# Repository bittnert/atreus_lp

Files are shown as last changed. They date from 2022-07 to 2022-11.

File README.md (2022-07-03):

# Atreus Low Profile Keyboard

This repository contains the files for a low profile variant of the atreus keyboard. THe original atreus keyboard can be found [[https://gitlab.com/technomancy/atreus][here]].

** The low profile atreus keyboard is still under development. The first PCB version has been ordered but not build or tested yet. **

The Keyboard uses Kailh Choc key switches which are soldered into a PCB. An addressable LED can be added to each key switch. Due to the size constraints, only 2020 LEDs (or smaller) can be used.

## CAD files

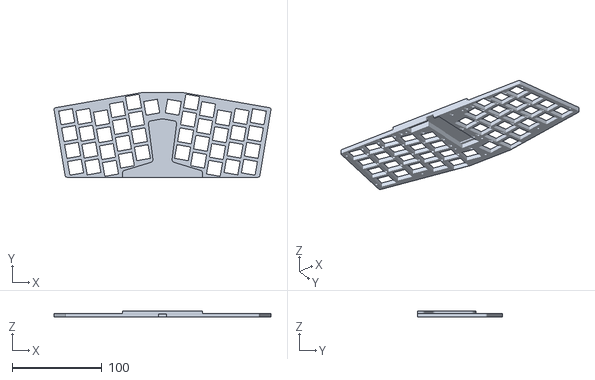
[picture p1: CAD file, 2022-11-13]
case/case.stl
241.4 x 94.0 x 6.60

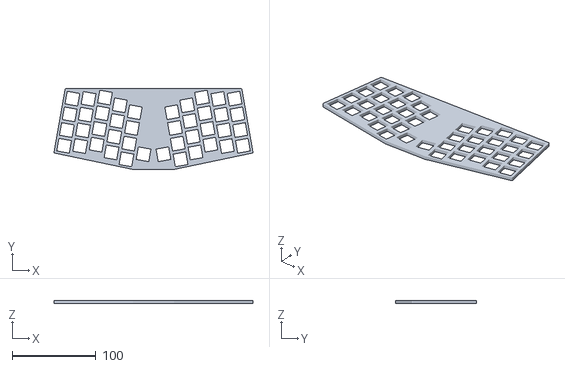
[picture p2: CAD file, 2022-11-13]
case/switch_plate.stl
237.0 x 96.3 x 3.50

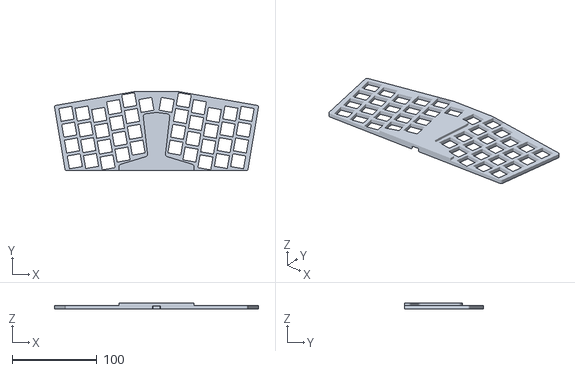
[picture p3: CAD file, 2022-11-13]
case/test_switch_plate.stl
241.4 x 94.0 x 6.60

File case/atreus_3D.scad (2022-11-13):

// -*- mode: c -*-
/* All distances are in mm. */

/* set output quality */
$fn = 50;

/* Distance between key centers. */
column_spacing   = 19;
row_spacing      = column_spacing;

/* This number should exceed row_spacing and column_spacing. The
 default gives a 1mm = (20mm - 19mm) gap between keycaps and cuts in
 the top plate.*/
key_hole_size = 20;

/* rotation angle; the angle between the halves is twice this
   number */
angle = 10;

/* The radius of screw holes. Holes will be slightly bigger due
   to the cut width. */
screw_hole_radius = 0;// 1.5;
/* Each screw hole is a hole in a "washer". How big these "washers"
   should be depends on the material used: this parameter and the
   `switch_hole_size` determine the spacer wall thickness. */
//washer_radius     = 4 * screw_hole_radius;
washer_radius = 1;

/* This constant allows tweaking the location of the screw holes near
   the USB cable. Only useful with small `angle` values. Try the value
   of 10 with angle=0. */
back_screw_hole_offset = 0;

/* Distance between halves. */
hand_separation        = 0;

/* The approximate size of switch holes. Used to determine how
   thick walls can be, i.e. how much room around each switch hole to
   leave. See spacer(). */
switch_hole_size = 14;

/* Sets whether the case should use notched holes. As far as I can
   tell these notches are not all that useful... */
use_notched_holes = false;

/* Number of rows and columns in the matrix. You need to update
   staggering_offsets if you change n_cols. */
n_rows = 4;
n_cols = 5;

/* Number of thumb keys (per hand), try 1 or 2. */
n_thumb_keys = 1;

/* The width of the USB cable hole in the spacer. */
cable_hole_width = 12;

/* Vertical column staggering offsets. The first element should
   be zero. */
staggering_offsets = [0, 5, 11, 6, 3];

/* Whether or not to split the spacer into quarters. */
quarter_spacer = false;

/* Where the top/bottom split of a quartered spacer will be. */
spacer_quartering_offset = 60;

module rz(angle, center=undef) {
  /* Rotate children `angle` degrees around `center`. */
  translate(center) {
    rotate(angle) {
      translate(-center) {
        for (i=[0:$children-1])
          children(i);
      }
    }
  }
}

/* Compute coordinates of a point obtained by rotating p angle degrees
   around center. Used to compute locations of screw holes near the
   USB cable hole. */
function rz_fun(p, angle, center) = [cos(angle) * (p[0] - center[0]) - sin(angle) * (p[1] - center[1]) + center[0],
                                     sin(angle) * (p[0] - center[0]) + cos(angle) * (p[1] - center[1])+ center[1]];

module switch_hole(position, notches=use_notched_holes) {
  /* Cherry MX switch hole with the center at `position`. Sizes come
     from the ErgoDox design. */
  hole_size    = 15.2;
  notch_width  = 3.5001;
  notch_offset = 4.2545;
  notch_depth  = 0.8128;
  translate(position) {
    union() {
        translate([0,0,-1])
      cube([hole_size, hole_size,50], center=true);
      if (notches == true) {
        translate([0, notch_offset,-1]) {
          cube([hole_size+2*notch_depth, notch_width,50], center=true);
        }
        translate([0, -notch_offset,-1]) {
          cube([hole_size+2*notch_depth, notch_width,50], center=true);
        }
      }
    }
  }
};

module regular_key(position, size) {
  /* Create a hole for a regular key. */
  translate(position) {
    cube([size, size,50], center=true);
  }
}

module thumb_key(position, size) {
  /* Create a hole for a 1x1.5 unit thumb key. */
  translate(position) {
    scale([1, 1.5]) {
      translate(-position) {
        regular_key(position, size);
      }
    }
  }
}

module column (bottom_position, switch_holes, key_size=key_hole_size) {
  /* Create a column of keys. */
  translate(bottom_position) {
    for (i = [0:(n_rows-1)]) {
      if (switch_holes == true) {
        switch_hole([0, i*column_spacing,-1]);
      } else {
        regular_key([0, i*column_spacing,-1], key_size);
      }
    }
  }
}

module rotate_half() {
  /* Rotate the right half of the keys around the top left corner of
     the thumb key. Assumes that the thumb key is a 1x1.5 key and that
     it is shifted 0.5*column_spacing up relative to the nearest column. */
  rotation_y_offset = 1.75 * column_spacing;
  for (i=[0:$children-1]) {
    rz(angle, [hand_separation, rotation_y_offset]) {
      children(i);
    }
  }
}

module add_hand_separation() {
  /* Shift everything right to get desired hand separation. */
  for (i=[0:$children-1]) {
    translate([0.5*hand_separation, /* we get back the full separation
                                       because of mirroring */
               0]) children(i);
  }
}

module right_half (switch_holes=true, key_size=key_hole_size) {
  /* Create switch holes or key holes for the right half of the
     keyboard. Different key_sizes are used in top_plate() and
     spacer(). */
  x_offset = 0.5 * row_spacing;
  y_offset = 0.5 * column_spacing;
  thumb_key_offset = y_offset + 0.5 * column_spacing;
  rotate_half() {
    add_hand_separation() {
      for (j=[0:(n_thumb_keys-1)]) {
        if (switch_holes == true) {
          switch_hole([x_offset + j*row_spacing, thumb_key_offset,-1]);
        } else {
          thumb_key([x_offset + j*row_spacing, thumb_key_offset,-1], key_size);
        }
      }
      for (j=[0:(n_cols-1)]) {
        column([x_offset + (j+n_thumb_keys)*row_spacing, y_offset + staggering_offsets[j]], switch_holes, key_size);
      }
    }
  }
}

module screw_hole(radius, offset_radius, position, direction) {
  /* Create a screw hole of radius `radius` at a location
     `offset_radius` from `position`, (diagonally), in the direction
     `direction`. Oh, what a mess this is. */
  /* direction is the 2-element vector specifying to which side of
     position to move to, [-1, -1] for bottom left, etc. */

  /* radius_offset is the offset in the x (or y) direction so that
     we're offset_radius from position */
  radius_offset = offset_radius / sqrt(2);
  /* key_hole_offset if the difference between key spacing and key
     hole edge */
  key_hole_offset = 0.5*(row_spacing - key_hole_size);
  x = position[0] + (radius_offset - key_hole_offset) * direction[0];
  y = position[1] + (radius_offset - key_hole_offset) * direction[1];
  translate([x,y,0]) {
    cylinder(r1=radius,r2=radius,h=4);
  }
}

module right_screw_holes(hole_radius) {
  /* coordinates of the back right screw hole before rotation... */
  back_right = [(n_cols+n_thumb_keys)*row_spacing,
               staggering_offsets[n_cols-1] + n_rows * column_spacing];
  /* and after */
  tmp = rz_fun(back_right, angle, [0, 2.25*column_spacing]);

  nudge = 0;

  rotate_half() {
    add_hand_separation() {
      screw_hole(hole_radius, washer_radius,
                 [row_spacing, 0],
                 [-nudge, -nudge]);
      screw_hole(hole_radius, washer_radius,
                 [(n_cols+n_thumb_keys)*row_spacing, staggering_offsets[n_cols-1]],
                 [nudge, -nudge]);
      #screw_hole(hole_radius, washer_radius,
                 back_right,
                 [nudge, nudge]);
    }
  }

  /* add the screw hole near the cable hole */
  *translate([washer_radius - tmp[0],
             back_screw_hole_offset]) {
    rotate_half() {
      add_hand_separation() {
        screw_hole(hole_radius,
                   washer_radius,
                   back_right,
                   [nudge, nudge]);
      }
    }
  }
}

module screw_holes(hole_radius) {
  /* Create all the screw holes. */
  right_screw_holes(hole_radius);
  mirror ([1,0,0]) { right_screw_holes(hole_radius); }
}

module left_half(switch_holes=true, key_size=key_hole_size) {
  mirror ([1,0,0]) { right_half(switch_holes, key_size); }
}

module bottom_plate() {
  /* bottom layer of the case */
  difference() {
    hull() { screw_holes(washer_radius); }
    screw_holes(screw_hole_radius);
  }
}

module top_plate() {
  /* top layer of the case */
  difference() {
    bottom_plate();
    right_half(false);
    left_half(false);
  }
}

module switch_plate() {
  /* the switch plate */
  difference() {
    bottom_plate();
    right_half();
    left_half();
  }
}

module spacer() {
  /* Create a spacer. */
  difference() {
    union() {
      difference() {
        bottom_plate();
        hull() {
          right_half(switch_holes=false, key_size=switch_hole_size + 3);
          left_half(switch_holes=false, key_size=switch_hole_size + 3);
        }
    /* add the USB cable hole: */
    translate([-0.5*cable_hole_width, 2*column_spacing,0]) {
      cube([cable_hole_width, (2*n_rows) * column_spacing,50]);
    }
      }
      screw_holes(washer_radius);
    }
    screw_holes(screw_hole_radius);
  }
}
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

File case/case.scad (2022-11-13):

include <rounded_polygon.scad>;
$fn=50;
thickness = 4;
switch_size = 15.4;

rand = 2;

battery_connector_height = 5;

battery_length = 27;
battery_width = 20;
battery_height = 4;

screw_diameter = 2;

corners = [
    [103 + 2.5*rand, 0 - rand, rand], 
    [116 + 2.5*rand, 73 + rand, rand], 
    [22 + rand,90 + rand, rand], 
    [0, 90 + rand, 0], 
    [0,0 - rand, 0]];

pcb_width = 19;
pcb_length = 34;
pcb_height = 3.5;

diode_positions = [
    [85.994, 3.4      , -280],
    [87.645, 13.433   , -280],
    [91.328,    33.372, -280],
    [93.995,    50.898, -280],
    [66.69,     3.781 , -280],
    [68.468,    13.433, -280],
    [71.516,    31.848, -280],
    [75.072,    51.279, -280],
    [46.37,     3.908 , -270],
    [49.545,    15.719, -280],
    [52.466,    33.499, -280],
    [55.895,    53.184, -280],
    [39.258,    3.908 , -270],
    [32.4,      28.927, -280],
    [35.194,    44.675, -280],
    [37.988,    61.566, -280],
    [21.351,    4.289 , -270],
    [12.461,    31.467, -280],
    [16.779,    50.136, -270],
    [19.827,    66.646, -280],
    [11.445,    50.136, -270],
    [-3.922,    66.011, -270],
    [-21.575,	14.576, -270],
    [-13.955,	36.293, -270],
    [-15.987,	50.009, -270],
    [-20.432,	67.027, -260],
    [-39.355,	3.4   , -270],
    [-32.751,	29.816, -270],
    [-36.434,	48.104, -260],
    [-39.482,	66.265, -260],
    [-47.356,	3.4   , -270],
    [-50.658,	20.672, -260],
    [-53.96	,   39.722, -260],
    [-56.627,	52.549, -260],
    [-66.914,	3.4   , -260],
    [-68.565,	12.163, -260],
    [-72.375,	34.007, -260],
    [-75.55	,   49.628, -260],
    [-86.218,	3.4   , -260],
    [-88.123,	13.814, -260],
    [-91.965,	34.107, -260],
    [-94.854,	50.898, -260]
];

switch_positions = [
    [ 96.677838, 9.177777],
    [99.977153, 27.889125],
    [103.276469, 46.600472],
    [106.575784, 65.311819],
    [77.445546,	9.52267],
    [80.744862,	28.234017],
    [84.044177,	46.945364],
    [87.343492,	65.656711],
    [57.865958,	7.897946],
    [61.165273,	26.609293],
    [64.464589,	45.320641],
    [67.763904,	64.031988],
    [40.1965, 17.106108],
    [43.495815,	35.817455],
    [46.795131,	54.528803],
    [50.094446,	73.24015],
    [22.353393,	25.329462],
    [25.652709,	44.040809],
    [28.952024,	62.752157],
    [32.25134, 81.463504],
    [11.977159,	75.89955]];

offsets = [5.5/cos(10), sqrt(2)*5.5/sin(10)];



pump_positions = [
    [16, 60.18, 3],
    [0, 63, 0],
    [0, 0 - rand, 0],
    [50 - offsets[0], 0 - rand, 0],
    [50- offsets[0], 5, 3],
    [22.353393 - 12, 25.329462 - 10, 3]

];

screw_position = [
    [70, 76],
    [34, 5],
    [16, 58],
    [0, 84],
    [106, 5],
    [117, 65]];

module diode_cutout(positions){
    for (position = positions)
    {
        translate([position[0], position[1], 0.75])
            rotate([0, 0, position[2]])
                cube([4.2, 2.2, 1.5], center=true);
    }
}

module pcb_cutout(){
    translate([0,pcb_length/2 - 17.878, battery_connector_height/2])
    cube([pcb_width, pcb_length, battery_connector_height], center= true);
    translate([0, -pcb_length/2, pcb_height/2])
    cube([9, 20, pcb_height], center=true);
}

module battery_connector_cutout(){ 
    rotate([0, 0, 90])
    translate([2,0,0])
    cube([8, 30, battery_connector_height]);
    translate([-4, 2,0])
    cube([8,50,battery_connector_height]);
}

module copy_mirror(vec){
    children();
    mirror(vec) children();
}

module switch_holes(positions){
    for (position = positions)
    {
        translate([position[0], position[1], 0])
            rotate([0, 0, -10])
            cube(switch_size, center= true);
    }
}

module screw_holes(positions){
    for (position = positions)
    {
        translate([position[0], position[1], -thickness/2])
            cylinder(thickness +1.5, r=screw_diameter/2);
    }
}

module battery_cutout(){
    translate([-battery_width/2, pcb_length - 0.1, 0])
    {
        cube([battery_width, battery_length, battery_height]);
        cube([battery_width, battery_length - 3, battery_connector_height]);
    }
}



difference(){
    union(){
        copy_mirror([1,0,0])
            linear_extrude(thickness)
                polygon(polyRound(corners, 50));
        copy_mirror([1,0,0])
            linear_extrude(6.6)
                polygon(polyRound(pump_positions, 50));
    }
    battery_cutout();
    copy_mirror([1, 0, 0])
        switch_holes(switch_positions);
    copy_mirror([1, 0, 0])
        #screw_holes(screw_position);
    translate([0, 17.878, 0])
        pcb_cutout();
    translate([0, -2, 0])
    battery_connector_cutout();
    diode_cutout(diode_positions);
}

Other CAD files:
case/rounded_polygon.scad

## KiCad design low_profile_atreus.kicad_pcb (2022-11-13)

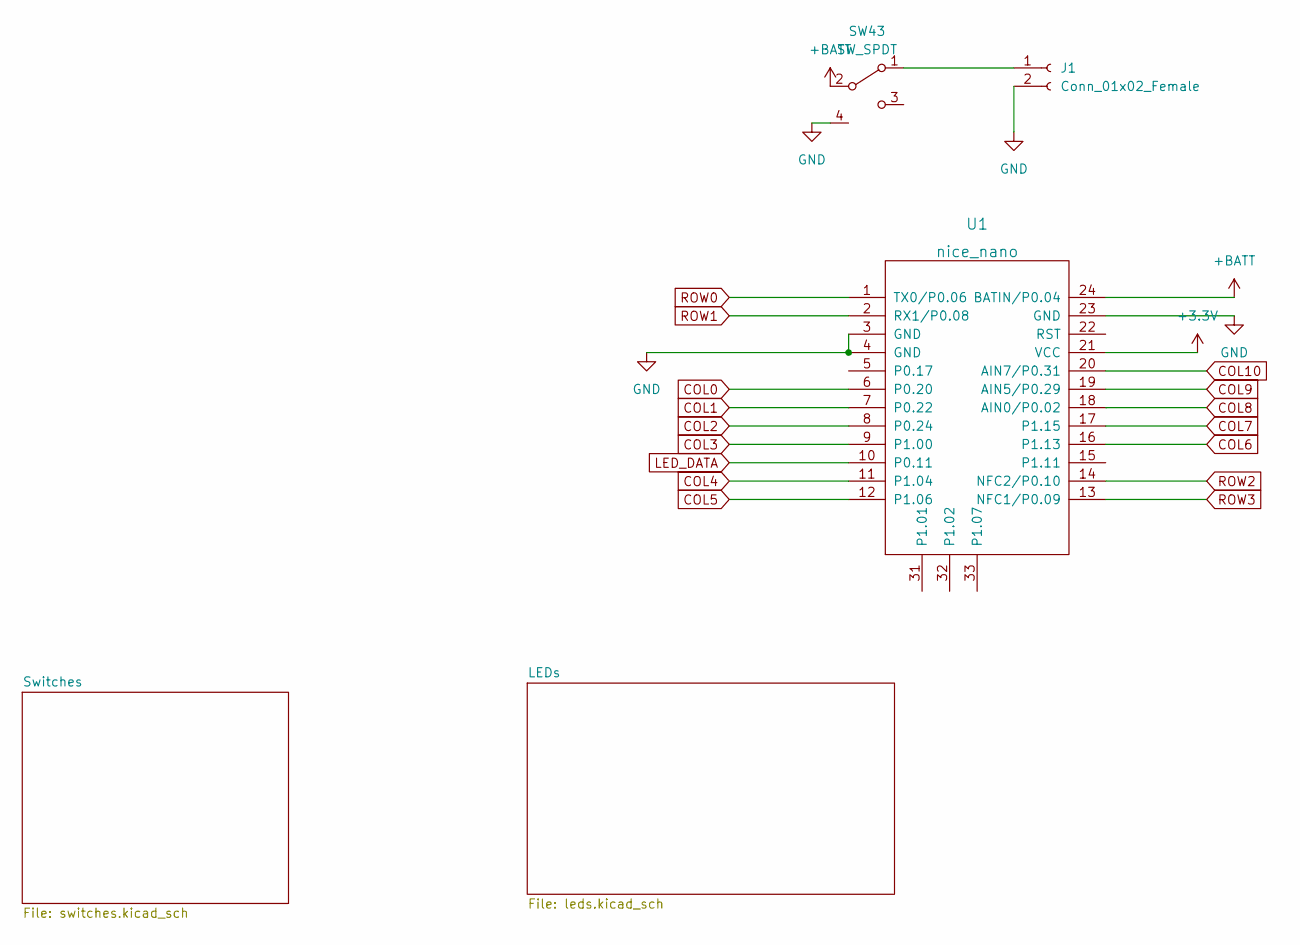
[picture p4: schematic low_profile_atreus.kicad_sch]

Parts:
J1: Conn_01x02_Female; JST_PH_S2B-PH-K_1x02_P2.00mm_Horizontal
SW43: SW_SPDT; MSK12C02
U1: nice_nano

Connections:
+3V3: U1.21 (VCC); also elsewhere on the board
+BATT: SW43.2 (B), U1.24 (BATIN/P0.04)
COL0: U1.6 (P0.20); also elsewhere on the board
COL1: U1.7 (P0.22); also elsewhere on the board
COL2: U1.8 (P0.24); also elsewhere on the board
COL3: U1.9 (P1.00); also elsewhere on the board
COL4: U1.11 (P1.04); also elsewhere on the board
COL5: U1.12 (P1.06); also elsewhere on the board
COL6: U1.16 (P1.13); also elsewhere on the board
COL7: U1.17 (P1.15); also elsewhere on the board
COL8: U1.18 (AIN0/P0.02); also elsewhere on the board
COL9: U1.19 (AIN5/P0.29); also elsewhere on the board
COL10: U1.20 (AIN7/P0.31); also elsewhere on the board
GND: J1.2, SW43.4 (GND), U1.3 (GND), U1.4 (GND), U1.23 (GND); also elsewhere on the board
LED_DATA: U1.10 (P0.11); also elsewhere on the board
unnamed: J1.1, SW43.1 (A)
ROW0: U1.1 (TX0/P0.06); also elsewhere on the board
ROW1: U1.2 (RX1/P0.08); also elsewhere on the board
ROW2: U1.14 (NFC2/P0.10); also elsewhere on the board
ROW3: U1.13 (NFC1/P0.09); also elsewhere on the board

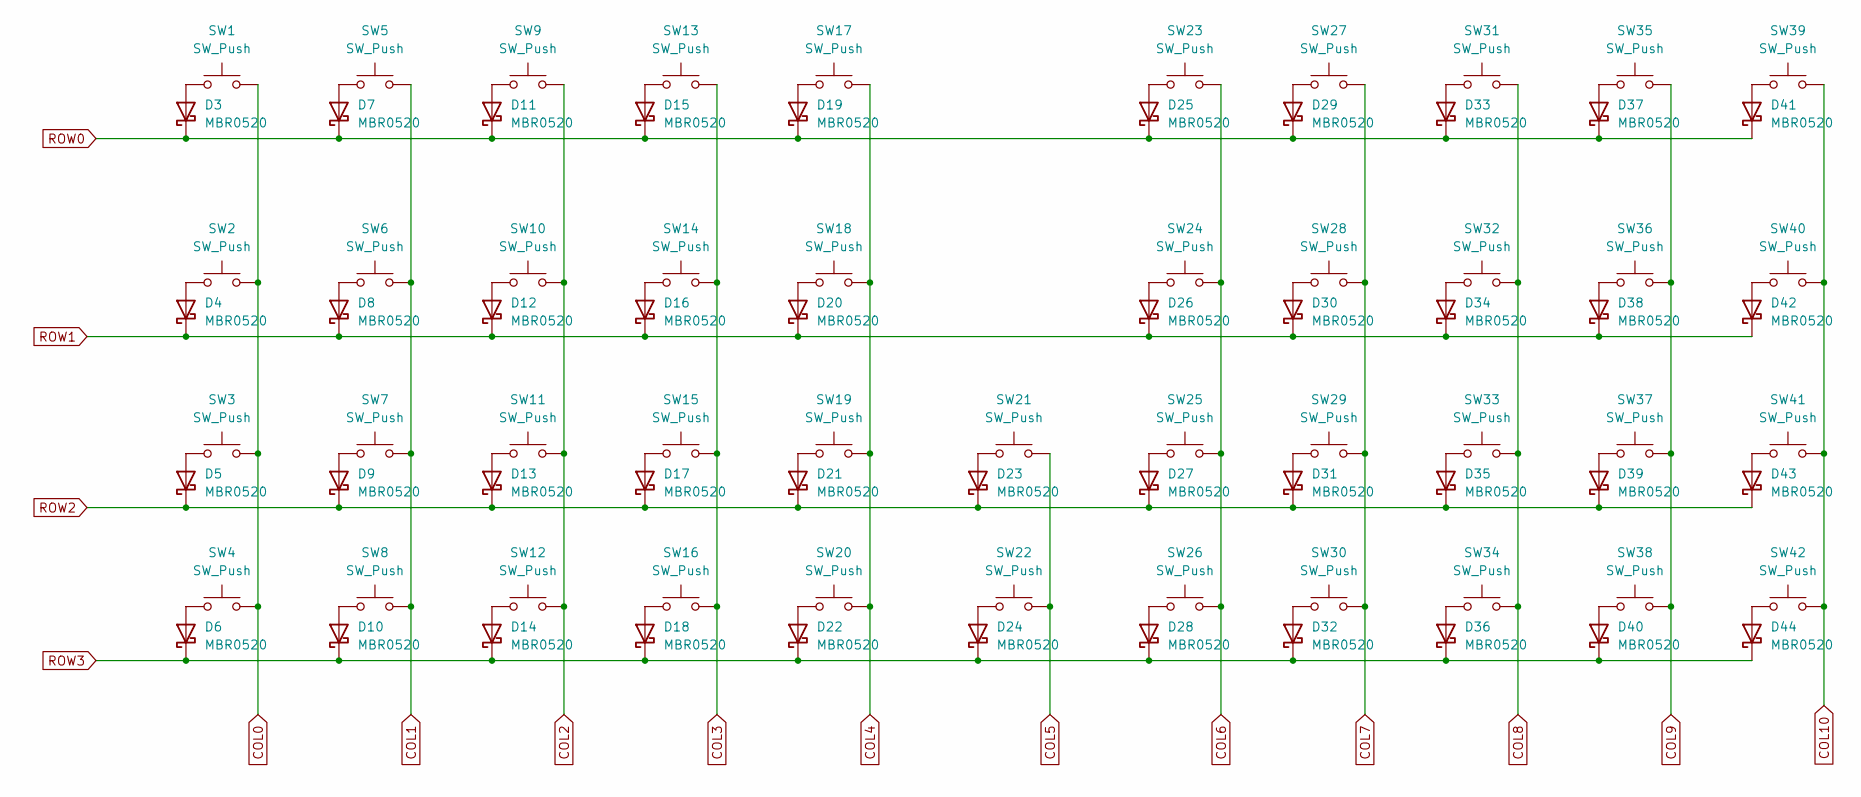
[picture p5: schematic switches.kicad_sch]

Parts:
D3, D4, D5, D6, D7, D8, D9, D10, D11, D12, D13, D14, D15, D16, D17, D18, D19, D20, D21, D22, D23, D24, D25, D26, D27, D28, D29, D30, D31, D32, D33, D34, D35, D36, D37, D38, D39, D40, D41, D42, D43, D44: MBR0520; D_SOD-123
SW1, SW2, SW3, SW4, SW5, SW6, SW7, SW8, SW9, SW10, SW11, SW12, SW13, SW14, SW15, SW16, SW17, SW18, SW19, SW20, SW21, SW22, SW23, SW24, SW25, SW26, SW27, SW28, SW29, SW30, SW31, SW32, SW33, SW34, SW35, SW36, SW37, SW38, SW39, SW40, SW41, SW42: SW_Push; SW_PG1350

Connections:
COL0: SW1.2, SW2.2, SW3.2, SW4.2; also elsewhere on the board
COL1: SW5.2, SW6.2, SW7.2, SW8.2; also elsewhere on the board
COL2: SW9.2, SW10.2, SW11.2, SW12.2; also elsewhere on the board
COL3: SW13.2, SW14.2, SW15.2, SW16.2; also elsewhere on the board
COL4: SW17.2, SW18.2, SW19.2, SW20.2; also elsewhere on the board
COL5: SW21.2, SW22.2; also elsewhere on the board
COL6: SW23.2, SW24.2, SW25.2, SW26.2; also elsewhere on the board
COL7: SW27.2, SW28.2, SW29.2, SW30.2; also elsewhere on the board
COL8: SW31.2, SW32.2, SW33.2, SW34.2; also elsewhere on the board
COL9: SW35.2, SW36.2, SW37.2, SW38.2; also elsewhere on the board
COL10: SW39.2, SW40.2, SW41.2, SW42.2; also elsewhere on the board
unnamed: D3.2 (A), SW1.1
unnamed: D4.2 (A), SW2.1
unnamed: D5.2 (A), SW3.1
unnamed: D6.2 (A), SW4.1
unnamed: D7.2 (A), SW5.1
unnamed: D8.2 (A), SW6.1
unnamed: D9.2 (A), SW7.1
unnamed: D10.2 (A), SW8.1
unnamed: D11.2 (A), SW9.1
unnamed: D12.2 (A), SW10.1
unnamed: D13.2 (A), SW11.1
unnamed: D14.2 (A), SW12.1
unnamed: D15.2 (A), SW13.1
unnamed: D16.2 (A), SW14.1
unnamed: D17.2 (A), SW15.1
unnamed: D18.2 (A), SW16.1
unnamed: D19.2 (A), SW17.1
unnamed: D20.2 (A), SW18.1
unnamed: D21.2 (A), SW19.1
unnamed: D22.2 (A), SW20.1
unnamed: D23.2 (A), SW21.1
unnamed: D24.2 (A), SW22.1
unnamed: D25.2 (A), SW23.1
unnamed: D26.2 (A), SW24.1
unnamed: D27.2 (A), SW25.1
unnamed: D28.2 (A), SW26.1
unnamed: D29.2 (A), SW27.1
unnamed: D30.2 (A), SW28.1
unnamed: D31.2 (A), SW29.1
unnamed: D32.2 (A), SW30.1
unnamed: D33.2 (A), SW31.1
unnamed: D34.2 (A), SW32.1
unnamed: D35.2 (A), SW33.1
unnamed: D36.2 (A), SW34.1
unnamed: D37.2 (A), SW35.1
unnamed: D38.2 (A), SW36.1
unnamed: D39.2 (A), SW37.1
unnamed: D40.2 (A), SW38.1
unnamed: D41.2 (A), SW39.1
unnamed: D42.2 (A), SW40.1
unnamed: D43.2 (A), SW41.1
unnamed: D44.2 (A), SW42.1
ROW0: D3.1 (K), D7.1 (K), D11.1 (K), D15.1 (K), D19.1 (K), D25.1 (K), D29.1 (K), D33.1 (K), D37.1 (K), D41.1 (K); also elsewhere on the board
ROW1: D4.1 (K), D8.1 (K), D12.1 (K), D16.1 (K), D20.1 (K), D26.1 (K), D30.1 (K), D34.1 (K), D38.1 (K), D42.1 (K); also elsewhere on the board
ROW2: D5.1 (K), D9.1 (K), D13.1 (K), D17.1 (K), D21.1 (K), D23.1 (K), D27.1 (K), D31.1 (K), D35.1 (K), D39.1 (K), D43.1 (K); also elsewhere on the board
ROW3: D6.1 (K), D10.1 (K), D14.1 (K), D18.1 (K), D22.1 (K), D24.1 (K), D28.1 (K), D32.1 (K), D36.1 (K), D40.1 (K), D44.1 (K); also elsewhere on the board

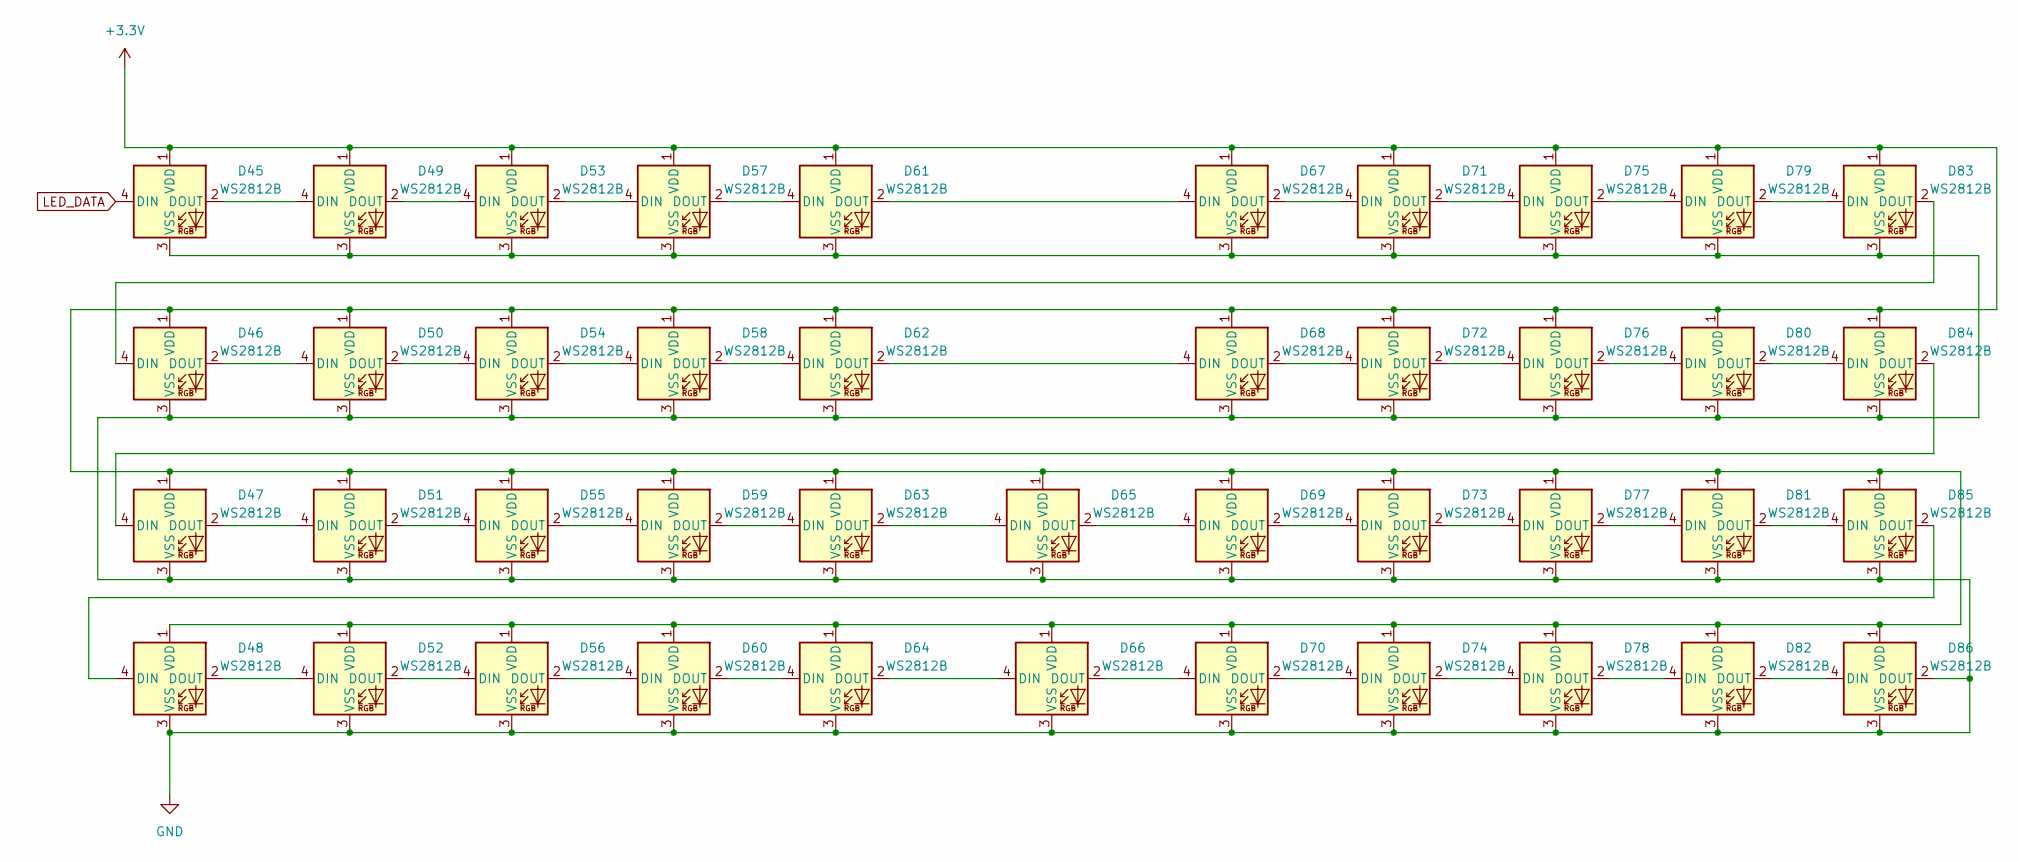
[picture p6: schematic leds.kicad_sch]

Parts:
D45, D46, D47, D48, D49, D50, D51, D52, D53, D54, D55, D56, D57, D58, D59, D60, D61, D62, D63, D64, D65, D66, D67, D68, D69, D70, D71, D72, D73, D74, D75, D76, D77, D78, D79, D80, D81, D82, D83, D84, D85, D86: WS2812B; LED_Cree-PLCC4_2x2mm_CW

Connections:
+3V3: D45.1 (VDD), D46.1 (VDD), D47.1 (VDD), D48.1 (VDD), D49.1 (VDD), D50.1 (VDD), D51.1 (VDD), D52.1 (VDD), D53.1 (VDD), D54.1 (VDD), D55.1 (VDD), D56.1 (VDD), D57.1 (VDD), D58.1 (VDD), D59.1 (VDD), D60.1 (VDD), D61.1 (VDD), D62.1 (VDD), D63.1 (VDD), D64.1 (VDD), D65.1 (VDD), D66.1 (VDD), D67.1 (VDD), D68.1 (VDD), D69.1 (VDD), D70.1 (VDD), D71.1 (VDD), D72.1 (VDD), D73.1 (VDD), D74.1 (VDD), D75.1 (VDD), D76.1 (VDD), D77.1 (VDD), D78.1 (VDD), D79.1 (VDD), D80.1 (VDD), D81.1 (VDD), D82.1 (VDD), D83.1 (VDD), D84.1 (VDD), D85.1 (VDD), D86.1 (VDD); also elsewhere on the board
GND: D45.3 (VSS), D46.3 (VSS), D47.3 (VSS), D48.3 (VSS), D49.3 (VSS), D50.3 (VSS), D51.3 (VSS), D52.3 (VSS), D53.3 (VSS), D54.3 (VSS), D55.3 (VSS), D56.3 (VSS), D57.3 (VSS), D58.3 (VSS), D59.3 (VSS), D60.3 (VSS), D61.3 (VSS), D62.3 (VSS), D63.3 (VSS), D64.3 (VSS), D65.3 (VSS), D66.3 (VSS), D67.3 (VSS), D68.3 (VSS), D69.3 (VSS), D70.3 (VSS), D71.3 (VSS), D72.3 (VSS), D73.3 (VSS), D74.3 (VSS), D75.3 (VSS), D76.3 (VSS), D77.3 (VSS), D78.3 (VSS), D79.3 (VSS), D80.3 (VSS), D81.3 (VSS), D82.3 (VSS), D83.3 (VSS), D84.3 (VSS), D85.3 (VSS), D86.2 (DOUT), D86.3 (VSS); also elsewhere on the board
LED_DATA: D45.4 (DIN); also elsewhere on the board
unnamed: D45.2 (DOUT), D49.4 (DIN)
unnamed: D46.2 (DOUT), D50.4 (DIN)
unnamed: D46.4 (DIN), D83.2 (DOUT)
unnamed: D47.2 (DOUT), D51.4 (DIN)
unnamed: D47.4 (DIN), D84.2 (DOUT)
unnamed: D48.2 (DOUT), D52.4 (DIN)
unnamed: D48.4 (DIN), D85.2 (DOUT)
unnamed: D49.2 (DOUT), D53.4 (DIN)
unnamed: D50.2 (DOUT), D54.4 (DIN)
unnamed: D51.2 (DOUT), D55.4 (DIN)
unnamed: D52.2 (DOUT), D56.4 (DIN)
unnamed: D53.2 (DOUT), D57.4 (DIN)
unnamed: D54.2 (DOUT), D58.4 (DIN)
unnamed: D55.2 (DOUT), D59.4 (DIN)
unnamed: D56.2 (DOUT), D60.4 (DIN)
unnamed: D57.2 (DOUT), D61.4 (DIN)
unnamed: D58.2 (DOUT), D62.4 (DIN)
unnamed: D59.2 (DOUT), D63.4 (DIN)
unnamed: D60.2 (DOUT), D64.4 (DIN)
unnamed: D61.2 (DOUT), D67.4 (DIN)
unnamed: D62.2 (DOUT), D68.4 (DIN)
unnamed: D63.2 (DOUT), D65.4 (DIN)
unnamed: D64.2 (DOUT), D66.4 (DIN)
unnamed: D65.2 (DOUT), D69.4 (DIN)
unnamed: D66.2 (DOUT), D70.4 (DIN)
unnamed: D67.2 (DOUT), D71.4 (DIN)
unnamed: D68.2 (DOUT), D72.4 (DIN)
unnamed: D69.2 (DOUT), D73.4 (DIN)
unnamed: D70.2 (DOUT), D74.4 (DIN)
unnamed: D71.2 (DOUT), D75.4 (DIN)
unnamed: D72.2 (DOUT), D76.4 (DIN)
unnamed: D73.2 (DOUT), D77.4 (DIN)
unnamed: D74.2 (DOUT), D78.4 (DIN)
unnamed: D75.2 (DOUT), D79.4 (DIN)
unnamed: D76.2 (DOUT), D80.4 (DIN)
unnamed: D77.2 (DOUT), D81.4 (DIN)
unnamed: D78.2 (DOUT), D82.4 (DIN)
unnamed: D79.2 (DOUT), D83.4 (DIN)
unnamed: D80.2 (DOUT), D84.4 (DIN)
unnamed: D81.2 (DOUT), D85.4 (DIN)
unnamed: D82.2 (DOUT), D86.4 (DIN)

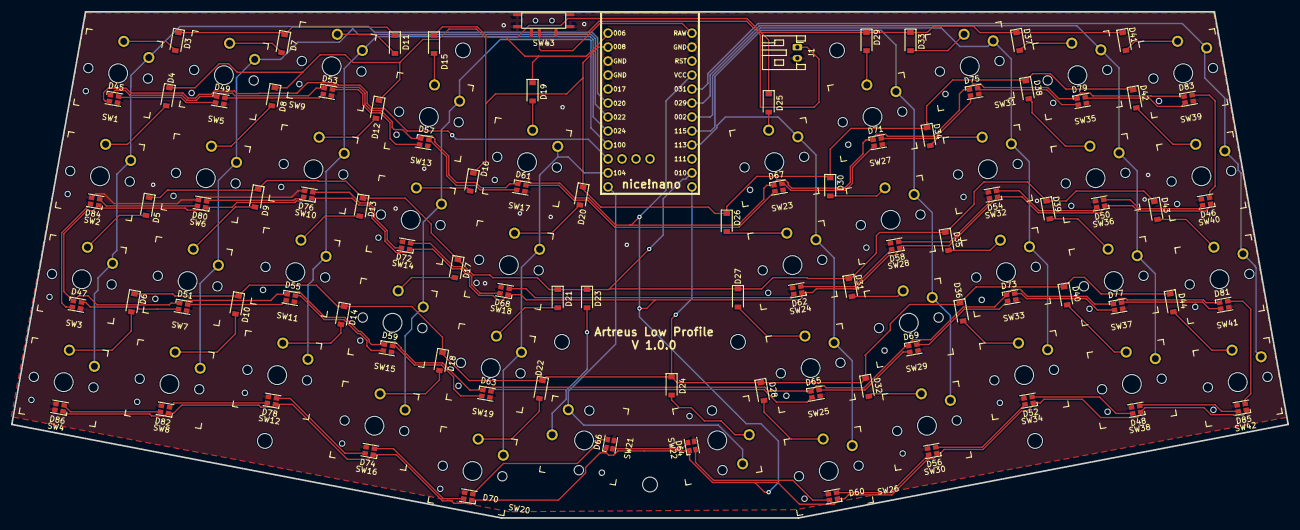
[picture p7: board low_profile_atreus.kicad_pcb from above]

Board: 2 copper layers, 232.0 x 92.0 mm, 136 parts (0 on the bottom side), 103 nets.

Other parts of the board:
Mounting Hole 2, Mounting Hole 3, Mounting Hole 4, Mounting Hole 5, Mounting Hole 6, Mounting Hole 7: MountingHole_2.7mm_M2.5
mounting Hole 1: MountingHole_2.7mm_M2.5
